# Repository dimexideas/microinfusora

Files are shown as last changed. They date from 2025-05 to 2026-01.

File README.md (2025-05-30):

# Microinfusora de Código Abierto

Micro Infusora de Código Abierto es un proyecto iniciado por un grupo de personas con intereses en desarrollo de tecnología en Ingeniería Biomédica en México.

Desarrollaremos un sistema de microinfusión que sea de código abierto y cuyo enfoque sea el educativo.

## Ojetivos Generales

1. Trabajar con estudiantes, profesores, profesionistas, organizaciones y cualquier otra entidad que quiera participar en el desarrollo de este proyecto.
2. Prepar a estudiantes y profesionistas de carreras de Ingeniería Biomédica y afines a trabajar en proyectos y retos con impacto real en la comunidad.
3. Sentar las bases para proyectos de desarrollo comunitario y servir como un modelo para otros proyectos futuros.

## Objetivos Específicos

1. Desarrollo de un marco teórico para el diseño, desarrollo, pruebas y producción de un dispositivo de microinfusión.
2. Desarrollar las capacidades técnicas para el diseño, desarrollo, pruebas y producción de un dispositivo de microinfusión.
3. Enfoque en seguridad, precisión, consistencia y costo.

## ⚠️ IMPORTANTE ⚠️

En la fase actual del proyecto ( Mayo 2025 ) NO buscamos que el trabajo que desarrollemos tenga una aplicación / uso / pruebas en seres vivos. Para poder avanzar a otro tipo de aplicaciones, será necesario primero el desarrollo de estudios y validaciones alrededor de investigación y validación de la mano de profesionales.

## Participantes

A continuación, la lista de personas que forman parte del proyecto:

* Cesar Terrazas
* Edgar Lopez
* Cesar Ortega
* Gustavo Muñoz
* Luis Duarte
* Sofia Piña 
* Anna Bórquez
* Javier Tanori
* Cristina Ochoa
* Jesus Esquerra
* Ximena Figueroa
* Dereck Palafox
* Victor Burruel  
* Angelica Pesqueira

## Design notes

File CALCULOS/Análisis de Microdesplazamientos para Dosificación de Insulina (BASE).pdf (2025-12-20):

# Análisis de Microdesplazamientos para Dosificación de Insulina con Resolución de 0.1 Unidades

Se necesita mover el embolo 0.0576mm para 0.1 Unidades

Se ocupa:

- Rosca de 1mm por vuelta
- Motor de 200 pasos por vuelta (1.8° por paso)
- Microstepping 16x (logra 3200 pasos por vuelta)

### ¿Cómo se lograron estos resultados?

Se realizaron los siguientes cálculos:

100 Unidades = 1mL

1 Unidades = 0.01mL

0.1 Unidades = 0.001 mL

1 Suponiendo que es de 1mL la jeringa, su diámetro estándar es de 4.7mm

Se usará la siguiente formula:

| Volumen = Area × Longitud
2. La cual convertimos en:
| Longitud = Volumen
| Area
3. Para poder sacar la longitud que tiene que mover el embolo calcularemos solamente el área, ya que, ya contamos con el volumen:
| Area = π × (
| 4.7
| 2

)

| 2 ≈ 17.34mm²
4. Ahora ya que sabemos el área y que 1mL = 1000mm³
| (es el volumen), procedemos a calcular la
longitud que se tiene que mover el embolo:
| Longitud = Volumen
| Area

Longitud =

1000
17.34 ≈ 57.64mm

### ¿Cuánto hay que mover para dosis más pequeñas?

- Para 1 Unidad (0.01mL):
57.64
100 ≈ 0.576mm
- Para 0.1 Unidades (0.001mL): 57.64
1000

≈ 0.0576mm

### ¿Como lograr esto?

Para lograr estos movimientos como lo mencione al principio, se necesitaría una rosca muy fina, el motor de 200 pasos y el microstepping 16x para así poder lograr 3200 pasos por vuelta.

Por ejemplo si usamos las especificaciones que puse al principio, el movimiento por cada micropaso sería:

1mm
3200 = 0.0003125mm

Lo cual es menor que 0.0576 mm, así que nos permite alcanzar la precisión que buscamos; y por ende tenemos el número de micro-pasos del motor necesarios para diferentes dosis:

micropasos =

Distancia que ocupa moverse el embolo correspondiente a la unidad cuanto se mueve el embolo por cada micropaso del motor

micropasos =

0.0576 mm
0.0003125 mm/micropaso

≈ 184

Para 0.1 unidades de insulina → ≈ 184 micro-pasos

Para 1 unidad de insulina → ≈ 1844 micro-pasos

Para 1 mL completo (100 unidades) → ≈ 184,444 micro-pasos

Estos mismos datos pueden ser alterados dependiendo del diámetro, motor, etc. Todo dependiendo de las especificaciones de lo que usaremos (este reporte solo nos sirve para tener una base y cambiar los datos a nuestras necesidades sin perder la precisión que buscamos).

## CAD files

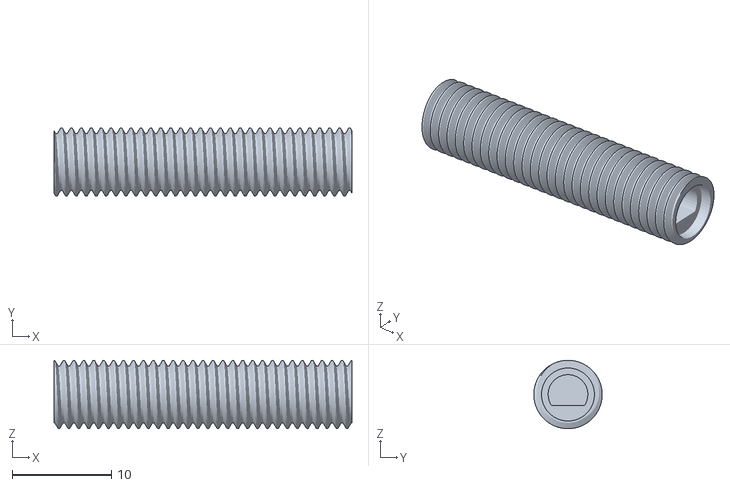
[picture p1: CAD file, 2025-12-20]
DISEÑO/Tornillo_Corregido v1.stl
30.0 x 6.88 x 6.88

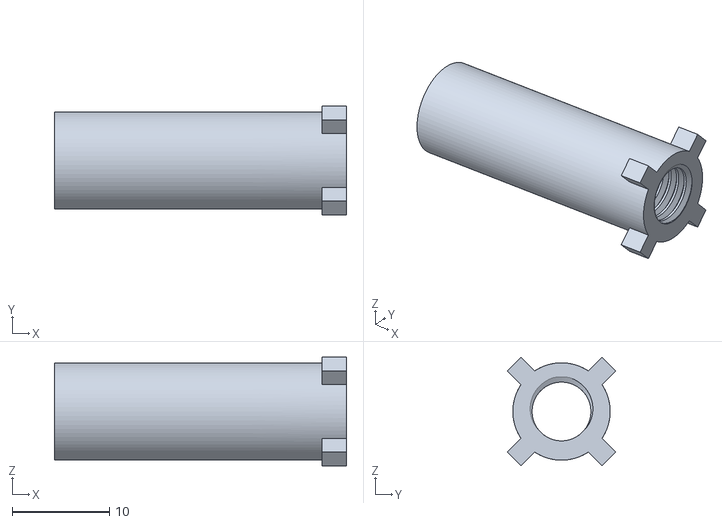
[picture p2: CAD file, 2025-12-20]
DISEÑO/shaft con patitas.stl
30.0 x 11.2 x 11.2

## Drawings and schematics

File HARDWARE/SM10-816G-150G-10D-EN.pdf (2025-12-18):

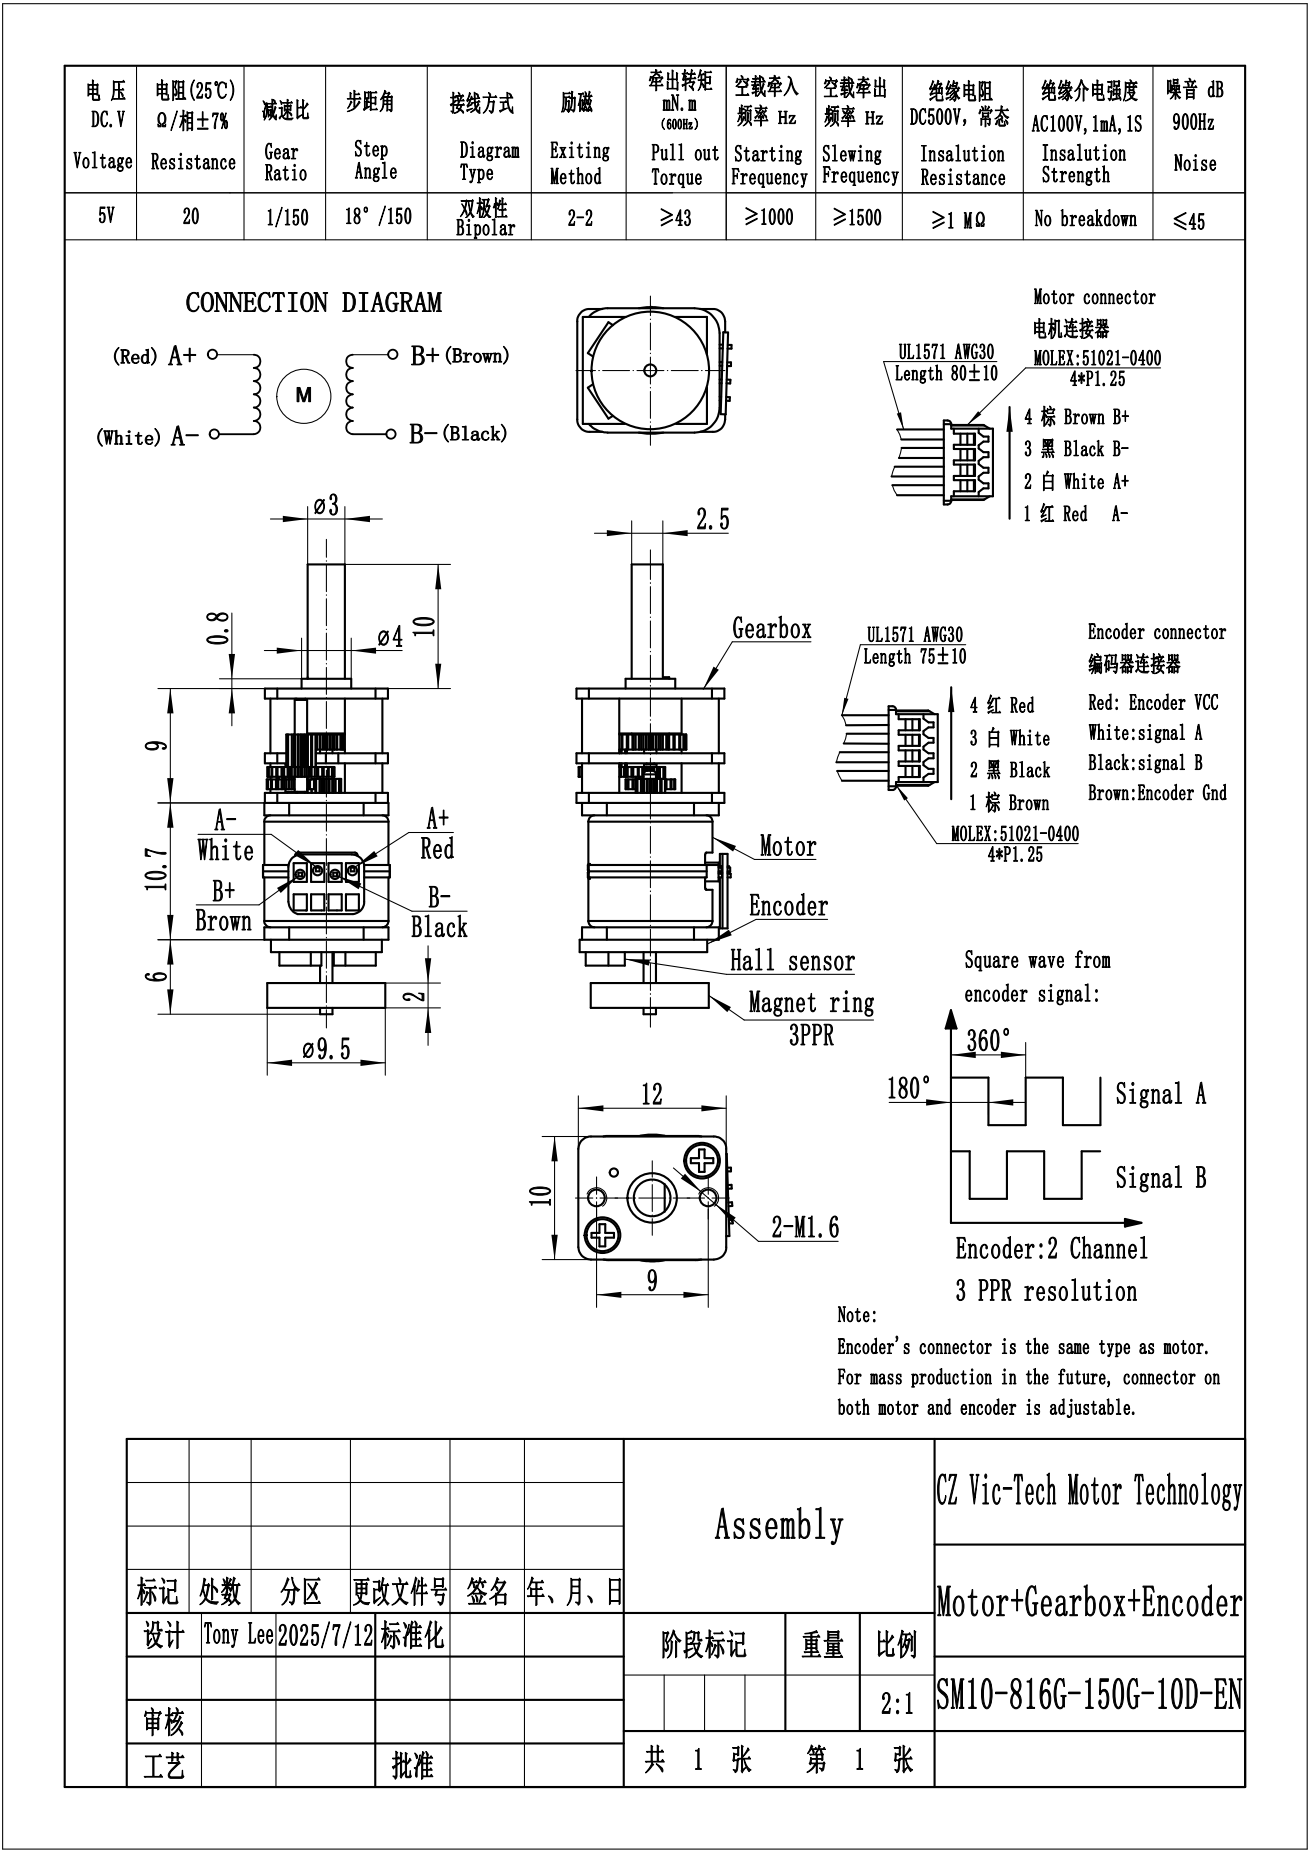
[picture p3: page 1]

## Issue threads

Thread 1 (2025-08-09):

Bug en prototipo en pantalla LCD al iniciar.

bustavo, 2025-08-09:
PROBLEMA:
Al iniciar el programa, muestra primero: "Inicializando microinfusora"
Posterior a esto, la pantalla muestra caracteres que no corresponden a lo esperado por el diagrama de flujo creado.

QUÉ DEBERÍA PASAR:
Después de el mensaje: "Inicializando microinfusora", debería proceder a hacer el chequeo del resto del sistema.

anaximenaf, 2025-08-11:
Al revisar el circuito electrónico, se encontraron 2 cables con falso contacto y fueron reemplazados. Después de esto, el problema se presenta después de mostrar en pantalla "Modo: Automático". También se encontró que al bajar el nivel de batería por debajo de 20% se muestran caracteres aleatorios.

Closed 2025-09-13.

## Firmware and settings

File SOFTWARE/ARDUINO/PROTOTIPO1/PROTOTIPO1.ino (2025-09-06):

//https://wokwi.com/projects/441378105660326913//
#include <LiquidCrystal.h>
#include <EEPROM.h>

// ===================== Hardware =====================
// LCD (RS, E, D4, D5, D6, D7)
LiquidCrystal lcd(12, 11, 5, 4, 3, 2);

// A4988
const int stepPin   = 6;
const int dirPin    = 7;
const int enablePin = 8;
const int ms1Pin = 9;
const int ms2Pin = 10;
const int ms3Pin = A3;

// Botones
const int BTN_BACK   = 13; // Escape/Atrás/Cancelar
const int BTN_OK     = A4; // Confirmar/Entrar
const int BTN_UP     = A5; // Subir
const int BTN_DOWN   = A1; // Bajar

// Otros
const int buzzer = A2;
const int voltagePin = A0; // batería simulada (potenciómetro)

// ===================== Parametría =====================
const int MICROSTEP = 16;            // 1/16 microstepping
const int BASE_STEPS_PER_U = 400;    // pasos por U a paso completo
const int STEPS_PER_U = BASE_STEPS_PER_U * MICROSTEP;

const uint32_t MIN_PULSE_US = 2;     // ancho mínimo de pulso (A4988 ~>1us)
const uint32_t BOLUS_SPEED_US = 900; // intervalo entre pasos para bolo rápido (~1.1k pps)
const uint32_t PRIME_SPEED_US = 1200;
const uint32_t MAX_PRIME_STEPS = 2000; // tope seguridad cebado

// Basal
float basalRate = 0.8f;             // U/h
// Límites
float bolusLimitPerDose = 10.0f;    // U máx por bolo
float bolusDailyLimit   = 50.0f;    // U máx por día (desde arranque)

// Simulación insulina/batería
float insulinRemaining = 300.0f;     // U
float batteryVoltage = 4.2f;         // Calculado desde A0
int   batteryPercent = 100;

// ===================== Persistencia EEPROM =====================
// (usa enteros escalados para evitar float en EEPROM)
const int EE_ADDR_BASAL_10X        = 0;   // uint16 (basal*10)
const int EE_ADDR_LIMIT_DOSE_10X   = 2;   // uint16
const int EE_ADDR_LIMIT_DAILY_10X  = 4;   // uint16

// ===================== Timing / Antirrebote =====================
struct Btn {
  uint8_t pin;
  bool last;
  uint32_t lastChange;
};
Btn btns[4] = {
  {BTN_BACK, true, 0},
  {BTN_OK,   true, 0},
  {BTN_UP,   true, 0},
  {BTN_DOWN, true, 0}
};
const uint16_t DEBOUNCE_MS = 35;
const uint16_t REPEAT_START_MS = 500;
const uint16_t REPEAT_RATE_MS  = 120;

bool pressedEdge(uint8_t index) {
  bool now = digitalRead(btns[index].pin);
  uint32_t t = millis();
  if (now != btns[index].last && (t - btns[index].lastChange) > DEBOUNCE_MS) {
    btns[index].last = now;
    btns[index].lastChange = t;
    // Botones con PULLUP: LOW = presionado
    return (now == LOW);
  }
  return false;
}
bool heldRepeat(uint8_t index) {
  // auto-repetición cuando se mantiene presionado
  static uint32_t startHeld[4] = {0,0,0,0};
  static uint32_t lastRpt[4]   = {0,0,0,0};
  bool now = (digitalRead(btns[index].pin) == LOW);
  uint32_t t = millis();
  if (pressedEdge(index)) { startHeld[index] = t; lastRpt[index]=t; return true; }
  if (now) {
    if (t - startHeld[index] > REPEAT_START_MS && t - lastRpt[index] > REPEAT_RATE_MS) {
      lastRpt[index] = t;
      return true;
    }
  }
  return false;
}

// ===================== Motor no bloqueante =====================
struct MotorJob {
  bool active = false;
  uint32_t stepIntervalUs = 1000;
  uint32_t lastStepUs = 0;
  uint32_t stepsRemaining = 0;
  uint8_t  type = 0; // 0=none,1=PRIME,2=BOLUS_FAST,3=BOLUS_EXT,4=BASAL
};
MotorJob job;

void motorEnable(bool en) { digitalWrite(enablePin, en ? LOW : HIGH); } // A4988 EN activo bajo
void motorPulse() {
  // Un pulso (HIGH->LOW). En Arduino, la pareja suele durar >1us sin delay
  digitalWrite(stepPin, HIGH);
  // delayMicroseconds(MIN_PULSE_US); // opcional
  digitalWrite(stepPin, LOW);
}
void startJob(uint8_t type, uint32_t steps, uint32_t intervalUs) {
  job.type = type;
  job.stepsRemaining = steps;
  job.stepIntervalUs = intervalUs;
  job.lastStepUs = micros();
  job.active = (steps > 0);
  motorEnable(true);
  digitalWrite(dirPin, HIGH);
}
void stopJob() {
  job.active = false;
  job.stepsRemaining = 0;
  job.type = 0;
  motorEnable(false);
}
void serviceMotor() {
  if (!job.active) return;
  uint32_t now = micros();
  if (now - job.lastStepUs >= job.stepIntervalUs) {
    motorPulse();
    job.lastStepUs = now;
    if (job.stepsRemaining > 0) {
      job.stepsRemaining--;
      if (job.stepsRemaining == 0) {
        stopJob();
      }
    }
  }
}

// ===================== Basal distribuida =====================
struct BasalTask {
  bool enabled = false;
  uint32_t stepIntervalUs = 0; // calculado desde basalRate
  uint32_t lastStepUs = 0;
} basalTask;

void recalcBasal() {
  if (basalRate <= 0.0f) { basalTask.enabled=false; return; }
  // pasos/hora = basalRate * STEPS_PER_U
  // intervalo por paso (us) = 3600e6 / pasosHora
  double stepsPerHour = (double)basalRate * (double)STEPS_PER_U;
  if (stepsPerHour < 1.0) stepsPerHour = 1.0;
  basalTask.stepIntervalUs = (uint32_t)(3600000000.0 / stepsPerHour);
  basalTask.enabled = true;
  basalTask.lastStepUs = micros();
}

void serviceBasal() {
  if (!basalTask.enabled || job.active) return; // no competir con un bolo/cebado
  uint32_t now = micros();
  if (now - basalTask.lastStepUs >= basalTask.stepIntervalUs) {
    // entregar 1 paso
    motorEnable(true);
    digitalWrite(dirPin, HIGH);
    motorPulse();
    basalTask.lastStepUs = now;
    // contabilidad de insulina
    insulinRemaining -= (1.0f / (float)STEPS_PER_U);
  }
}

// ===================== Bolo extendido / automático =====================
struct ExtendedBolus {
  bool active=false;
  uint32_t totalSteps=0;
  uint32_t stepsDelivered=0;
  uint32_t stepIntervalUs=0;
  uint32_t lastStepUs=0;
  uint32_t endMillis=0;
  bool repeating=false;
  uint32_t repeatEveryMs=0;
} ext;

void startExtended(float units, uint32_t durationMin) {
  if (units <= 0) return;
  uint32_t steps = (uint32_t)(units * STEPS_PER_U + 0.5f);
  if (steps == 0) return;
  uint64_t totalUs = (uint64_t)durationMin * 60000000ULL;
  uint32_t intervalUs = (uint32_t)(totalUs / steps);
  ext.active=true;
  ext.totalSteps = steps;
  ext.stepsDelivered = 0;
  ext.stepIntervalUs = (intervalUs == 0 ? 1 : intervalUs);
  ext.lastStepUs = micros();
  ext.endMillis = millis() + durationMin*60000UL;
}

void serviceExtended() {
  if (!ext.active || job.active) return; // no solapar con job rápido
  uint32_t nowUs = micros();
  if (nowUs - ext.lastStepUs >= ext.stepIntervalUs) {
    motorEnable(true);
    digitalWrite(dirPin, HIGH);
    motorPulse();
    ext.lastStepUs = nowUs;
    ext.stepsDelivered++;
    insulinRemaining -= (1.0f / (float)STEPS_PER_U);
    if (ext.stepsDelivered >= ext.totalSteps) {
      ext.active = false;
      motorEnable(false);
      if (ext.repeating && ext.repeatEveryMs > 0) {
        // reprogramar
        startExtended((float)ext.totalSteps/(float)STEPS_PER_U, (ext.repeatEveryMs/60000UL));
      }
    }
  }
}

void cancelAnyInfusion() {
  stopJob();
  ext.active = false;
  motorEnable(false);
  tone(buzzer, 1900, 120);
}

// ===================== Utilidades =====================
void beepOK()   { tone(buzzer, 1400, 80); }
void beepWarn() { tone(buzzer, 900,  120); }
void beepErr()  { tone(buzzer, 500,  200); }

void readBattery() {
  int v = analogRead(voltagePin);
  // Simula 3.0V .. 4.2V en el potenciómetro
  batteryVoltage = map(v, 0, 1023, 300, 420)/100.0;
  batteryPercent = map(v, 0, 1023, 0, 100);
  if (batteryPercent < 0) batteryPercent=0;
  if (batteryPercent > 100) batteryPercent=100;
}

// ===================== Menú / Estados =====================
enum State {
  ST_HOME,
  ST_MENU,
  ST_PRIME,
  ST_BOLUS_MANUAL,
  ST_BOLUS_MANUAL_EXTDUR,
  ST_BOLUS_CANCEL,
  ST_LIMITS,
  ST_BASAL,
  ST_AUTO_PROG,         // “X U en Y min, repetir cada Z”
  ST_CONFIRM_START
};
State state = ST_HOME;

int menuIndex = 0;
const int MENU_COUNT = 7;

float tmpUnits = 1.0f;   // buffer para selección de U
int   tmpMinutes = 10;   // buffer para selección de minutos
int   tmpRepeatMin = 0;  // 0 = no repetir

// Estadística simple
float dailyDelivered = 0.0f;

void drawHome() {
  lcd.clear();
  lcd.setCursor(0,0);
  lcd.print("Bat ");
  lcd.print(batteryPercent);
  lcd.print("%  Ins ");
  if (insulinRemaining < 0) insulinRemaining = 0;
  lcd.print((int)insulinRemaining);
  lcd.print("U");
  lcd.setCursor(0,1);
  lcd.print(ext.active ? "EXBolus ON   " : (job.active ? "Bolo/Cebado  " : "Listo         "));
}

void drawMenu() {
  lcd.clear();
  const char* items[MENU_COUNT] = {
    "Cebado",
    "Bolo manual",
    "Cancelar bolo",
    "Limitar bolo",
    "Infusion basal",
    "Auto programar",
    "Salir"
  };
  // Mostrar 2 líneas con cursor
  int next = (menuIndex+1) % MENU_COUNT;
  lcd.setCursor(0,0); lcd.print(">");
  lcd.print(items[menuIndex]);
  lcd.setCursor(0,1); lcd.print(" ");
  lcd.print(items[next]);
}

void eepromLoad() {
  uint16_t b10 = 0, l110=0, l210=0;
  EEPROM.get(EE_ADDR_BASAL_10X, b10);
  EEPROM.get(EE_ADDR_LIMIT_DOSE_10X, l110);
  EEPROM.get(EE_ADDR_LIMIT_DAILY_10X, l210);
  if (b10 > 0 && b10 < 500) basalRate = b10 / 10.0f;
  if (l110 >= 5 && l110 <= 500) bolusLimitPerDose = l110 / 10.0f;
  if (l210 >= 10 && l210 <= 1000) bolusDailyLimit = l210 / 10.0f;
  recalcBasal();
}

void eepromSave() {
  uint16_t b10 = (uint16_t)(basalRate*10.0f + 0.5f);
  uint16_t l110= (uint16_t)(bolusLimitPerDose*10.0f + 0.5f);
  uint16_t l210= (uint16_t)(bolusDailyLimit*10.0f + 0.5f);
  EEPROM.put(EE_ADDR_BASAL_10X,       b10);
  EEPROM.put(EE_ADDR_LIMIT_DOSE_10X,  l110);
  EEPROM.put(EE_ADDR_LIMIT_DAILY_10X, l210);
}

// ===================== Setup =====================
void setup() {
  pinMode(stepPin, OUTPUT);
  pinMode(dirPin, OUTPUT);
  pinMode(enablePin, OUTPUT);
  pinMode(ms1Pin, OUTPUT);
  pinMode(ms2Pin, OUTPUT);
  pinMode(ms3Pin, OUTPUT);

  pinMode(BTN_BACK, INPUT_PULLUP);
  pinMode(BTN_OK,   INPUT_PULLUP);
  pinMode(BTN_UP,   INPUT_PULLUP);
  pinMode(BTN_DOWN, INPUT_PULLUP);

  pinMode(buzzer, OUTPUT);

  // Microstepping 1/16
  digitalWrite(ms1Pin, HIGH);
  digitalWrite(ms2Pin, HIGH);
  digitalWrite(ms3Pin, HIGH);
  motorEnable(false);

  lcd.begin(16,2);
  lcd.print("Microinfusora");
  lcd.setCursor(0,1); lcd.print("Iniciando...");
  delay(900);
  eepromLoad();
  drawHome();
}

// ===================== Loop =====================
void loop() {
  // servicios en background
  readBattery();
  serviceMotor();
  serviceExtended();
  serviceBasal();

  // bloqueo por batería crítica
  if (batteryPercent < 5 || batteryVoltage < 3.30) {
    cancelAnyInfusion();
    lcd.setCursor(0,1);
    lcd.print("Bateria critica");
    delay(5);
    return;
  }

  // ---- Navegación / estados ----
  switch (state) {
    case ST_HOME: {
      // Entrar a menú
      if (pressedEdge(1)) { // OK
        state = ST_MENU;
        menuIndex = 0;
        drawMenu();
        beepOK();
      }
      // Cancelación rápida
      if (pressedEdge(0)) {
        cancelAnyInfusion();
        drawHome();
      }
      // Scroll para refrescar pantalla
      if (heldRepeat(2) || heldRepeat(3)) {
        drawHome();
      }
    } break;

    case ST_MENU: {
      if (heldRepeat(2)) { // UP
        menuIndex = (menuIndex - 1 + MENU_COUNT) % MENU_COUNT;
        drawMenu();
      }
      if (heldRepeat(3)) { // DOWN
        menuIndex = (menuIndex + 1) % MENU_COUNT;
        drawMenu();
      }
      if (pressedEdge(1)) { // OK
        beepOK();
        switch (menuIndex) {
          case 0: state = ST_PRIME; break;
          case 1: state = ST_BOLUS_MANUAL; tmpUnits = 1.0f; break;
          case 2: state = ST_BOLUS_CANCEL; break;
          case 3: state = ST_LIMITS; break;
          case 4: state = ST_BASAL; break;
          case 5: state = ST_AUTO_PROG; tmpUnits=1.0f; tmpMinutes=10; tmpRepeatMin=0; break;
          case 6: state = ST_HOME; drawHome(); break;
        }
      }
      if (pressedEdge(0)) { // BACK
        state = ST_HOME; drawHome();
      }
    } break;

    case ST_PRIME: {
      // Cebado configurable por pasos (U) o tiempo
      static bool asUnits = true; // alterna con OK
      static float primeUnits = 0.5f;
      static int   primeSecs  = 10;

      lcd.setCursor(0,0);
      lcd.print("Cebado ");
      lcd.print(asUnits ? "Unid" : "Tiempo");
      lcd.setCursor(0,1);
      if (asUnits) {
        lcd.print(primeUnits,1); lcd.print("U  OK=Go ");
      } else {
        lcd.print(primeSecs); lcd.print("s  OK=Go ");
      }

      if (heldRepeat(2)) { // UP
        if (asUnits) { if (primeUnits < 5.0f) primeUnits += 0.1f; }
        else          { if (primeSecs  < 60)   primeSecs  += 1;   }
        lcd.setCursor(0,1); lcd.print("                ");
      }
      if (heldRepeat(3)) { // DOWN
        if (asUnits) { if (primeUnits > 0.1f) primeUnits -= 0.1f; }
        else          { if (primeSecs  > 1)    primeSecs  -= 1;   }
        lcd.setCursor(0,1); lcd.print("                ");
      }
      if (pressedEdge(1)) { // OK -> iniciar
        uint32_t steps = asUnits ? (uint32_t)(primeUnits*STEPS_PER_U+0.5f)
                                 : (uint32_t)((1000000UL*primeSecs)/PRIME_SPEED_US);
        if (steps > MAX_PRIME_STEPS) steps = MAX_PRIME_STEPS;
        if (insulinRemaining < (float)steps/(float)STEPS_PER_U) { beepErr(); break; }
        startJob(1, steps, PRIME_SPEED_US);
        insulinRemaining -= (float)steps/(float)STEPS_PER_U;
        dailyDelivered   += (float)steps/(float)STEPS_PER_U;
        state = ST_HOME; drawHome();
      }
      if (pressedEdge(0)) { // BACK
        state = ST_MENU; drawMenu();
      }
      // alterna unidades/tiempo con pulsación larga OK
      static uint32_t lastOk = 0;
      if (digitalRead(BTN_OK)==LOW) {
        if (millis()-lastOk>700) { asUnits = !asUnits; lastOk=millis(); lcd.clear(); }
      } else lastOk=millis();
    } break;

    case ST_BOLUS_MANUAL: {
      // Paso 1: elegir unidades
      lcd.setCursor(0,0); lcd.print("Bolo manual U:");
      lcd.setCursor(0,1); lcd.print("  "); lcd.print(tmpUnits,1); lcd.print("U");
      if (heldRepeat(2)) { if (tmpUnits < bolusLimitPerDose) tmpUnits += 0.1f; }
      if (heldRepeat(3)) { if (tmpUnits > 0.1f)              tmpUnits -= 0.1f; }
      if (pressedEdge(1)) { // OK -> escoger tipo
        state = ST_BOLUS_MANUAL_EXTDUR;
        lcd.clear();
      }
      if (pressedEdge(0)) { state = ST_MENU; drawMenu(); }
    } break;

    case ST_BOLUS_MANUAL_EXTDUR: {
      // Elegir rápido o extendido (duración)
      static bool extended = false;
      lcd.setCursor(0,0); lcd.print(extended ? "Extendido" : "Rapido");
      lcd.setCursor(0,1);
      if (extended) { lcd.print("Dur: "); lcd.print(tmpMinutes); lcd.print(" min"); }
      else          { lcd.print("OK=Iniciar  "); }

      if (heldRepeat(2)) { // UP
        if (extended && tmpMinutes < 240) tmpMinutes++;
        else extended = true;
      }
      if (heldRepeat(3)) { // DOWN
        if (extended && tmpMinutes > 1) tmpMinutes--;
        else extended = false;
      }
      if (pressedEdge(1)) { // OK -> iniciar
        // Chequeos de seguridad
        if (tmpUnits > bolusLimitPerDose) { beepErr(); break; }
        if (dailyDelivered + tmpUnits > bolusDailyLimit) { beepErr(); break; }
        if (insulinRemaining < tmpUnits) { beepErr(); break; }

        if (extended) {
          startExtended(tmpUnits, tmpMinutes);
          dailyDelivered   += tmpUnits;
          insulinRemaining -= tmpUnits;
        } else {
          uint32_t steps = (uint32_t)(tmpUnits*STEPS_PER_U+0.5f);
          startJob(2, steps, BOLUS_SPEED_US);
          dailyDelivered   += tmpUnits;
          insulinRemaining -= tmpUnits;
        }
        state = ST_HOME; drawHome();
      }
      if (pressedEdge(0)) { state = ST_BOLUS_MANUAL; lcd.clear(); }
    } break;

    case ST_BOLUS_CANCEL: {
      cancelAnyInfusion();
      state = ST_MENU; drawMenu();
    } break;

    case ST_LIMITS: {
      static uint8_t page=0; // 0=per-dose,1=daily
      lcd.setCursor(0,0);
      lcd.print(page==0 ? "Limite x Bolo" : "Limite Diario");
      lcd.setCursor(0,1);
      lcd.print(page==0 ? bolusLimitPerDose : bolusDailyLimit);
      lcd.print("U     ");

      if (heldRepeat(2)) { if (page==0) bolusLimitPerDose += 0.5f; else bolusDailyLimit += 1.0f; }
      if (heldRepeat(3)) { if (page==0 && bolusLimitPerDose>0.5f) bolusLimitPerDose -= 0.5f;
                           if (page==1 && bolusDailyLimit>1.0f)   bolusDailyLimit   -= 1.0f; }
      if (pressedEdge(1)) { // OK -> cambiar página o guardar
        if (page==0) page=1;
        else { eepromSave(); page=0; beepOK(); }
        lcd.clear();
      }
      if (pressedEdge(0)) { state = ST_MENU; drawMenu(); }
    } break;

    case ST_BASAL: {
      lcd.setCursor(0,0); lcd.print("Basal: "); lcd.print(basalRate,1); lcd.print("U/h");
      lcd.setCursor(0,1); lcd.print("OK=Guardar  ");
      if (heldRepeat(2)) { if (basalRate < 5.0f) basalRate += 0.1f; }
      if (heldRepeat(3)) { if (basalRate > 0.0f) basalRate -= 0.1f; }
      if (pressedEdge(1)) { eepromSave(); recalcBasal(); state = ST_MENU; drawMenu(); }
      if (pressedEdge(0)) { state = ST_MENU; drawMenu(); }
    } break;

    case ST_AUTO_PROG: {
      // “manda X U en Y min, repetir cada Z min (0=una vez)”
      lcd.setCursor(0,0);
      lcd.print("U:"); lcd.print(tmpUnits,1);
      lcd.print(" T:"); lcd.print(tmpMinutes); lcd.print("m");
      lcd.setCursor(0,1);
      lcd.print("Rep: "); lcd.print(tmpRepeatMin); lcd.print("m  OK=Go");

      if (heldRepeat(2)) {
        // ciclo de edición: U -> T -> Rep
        static uint8_t field=0;
        // rotación de campo con OK largo
        if (digitalRead(BTN_OK)==LOW) { field=(field+1)%3; delay(180); }
        if (field==0 && tmpUnits < bolusLimitPerDose) tmpUnits+=0.1f;
        if (field==1 && tmpMinutes < 600) tmpMinutes++;
        if (field==2 && tmpRepeatMin < 600) tmpRepeatMin++;
      }
      if (heldRepeat(3)) {
        static uint8_t field=0;
        if (digitalRead(BTN_OK)==LOW) { field=(field+1)%3; delay(180); }
        if (field==0 && tmpUnits > 0.1f) tmpUnits-=0.1f;
        if (field==1 && tmpMinutes > 1) tmpMinutes--;
        if (field==2 && tmpRepeatMin > 0) tmpRepeatMin--;
      }
      if (pressedEdge(1)) {
        if (tmpUnits > bolusLimitPerDose) { beepErr(); break; }
        if (dailyDelivered + tmpUnits > bolusDailyLimit) { beepErr(); break; }
        if (insulinRemaining < tmpUnits) { beepErr(); break; }
        // programar como bolo extendido
        startExtended(tmpUnits, tmpMinutes);
        dailyDelivered   += tmpUnits;
        insulinRemaining -= tmpUnits;
        // configurar repetición
        ext.repeating = (tmpRepeatMin > 0);
        ext.repeatEveryMs = (uint32_t)tmpRepeatMin * 60000UL;
        state = ST_HOME; drawHome();
      }
      if (pressedEdge(0)) { state = ST_MENU; drawMenu(); }
    } break;

    case ST_CONFIRM_START:
      // (no usado en esta versión; se dejó hueco si quieres pantallas de confirmación)
      state = ST_HOME;
      break;
  }
}

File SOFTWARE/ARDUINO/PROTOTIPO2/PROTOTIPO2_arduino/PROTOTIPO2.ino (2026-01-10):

// https://wokwi.com/projects/449649246302984193//
#include <EEPROM.h>
#include <LiquidCrystal.h>

// LCD (RS, E, D4, D5, D6, D7)
// LCD (RS, E, D4, D5, D6, D7)
// LCD (RS, E, D4, D5, D6, D7)
LiquidCrystal lcd(12, 13, 4, 5, 6, 7);

// A4988
// A4988
// A4988
const int stepPin = 9;   // PASOS. Cada pulso, avanza un paso.
const int dirPin = 8;    // DIRECCIÓN. 0 = Antihorario, 1 = Horario.
const int enablePin = 2; // ACTIVACION. 0 = Activo, 1 = Inactivo.
// const int ms1Pin = 9;    // TAMAÑO DE PASO. 0 = 1/16, 1 = 1/8, 2 = 1/4, 3 = 1/2, 4 = 1/1.
// const int ms2Pin = 10;   // TAMAÑO DE PASO. 0 = 1/16, 1 = 1/8, 2 = 1/4, 3 = 1/2, 4 = 1/1.
// const int ms3Pin = A3;   // TAMAÑO DE PASO. 0 = 1/16, 1 = 1/8, 2 = 1/4, 3 = 1/2, 4 = 1/1.

// VARIABLES MOTOR & INSULINA.
// VARIABLES MOTOR & INSULINA.
// VARIABLES MOTOR & INSULINA.
int curStep = 0;         // PASO ACTUAL.
const float reservoirCapacity = 300; // CONFIGURACION DE CAPACIDAD DE RESERVORIO.
float reservoirLevel = reservoirCapacity; // NIVEL DE RESERVORIO.
float stepUnits = 0.1; // UNIDADES DE INSULINA POR PASOS DE MOTOR.

// VARIABLES PERFIL BASAL.
// VARIABLES PERFIL BASAL.
// VARIABLES PERFIL BASAL.

const uint8_t BASAL_SLOTS = 48;
const uint8_t MIN_PER_SLOT = 30;
const uint16_t VALUE10_MAX = 100;

uint16_t basal10[BASAL_SLOTS];
uint8_t editingStartSlot = 0;
uint8_t editingEndSlot = 0;
uint16_t editingValue10 = 0;

void lcdPrintHHMM_fromSlot(uint8_t slot) {
  uint16_t minutes = (uint16_t)slot * MIN_PER_SLOT; // 0..1440
  uint8_t hh = minutes / 60;
  uint8_t mm = minutes % 60;

  if (hh < 10) lcd.print("0");
  lcd.print(hh);
  lcd.print(":");
  if (mm < 10) lcd.print("0");
  lcd.print(mm);
}

void nudgeEndSlot(int8_t dir) { // dir = +1 or -1
  int16_t next = (int16_t)editingEndSlot + dir;

  if (next < (int16_t)editingStartSlot) next = editingStartSlot;
  if (next > 48) next = 48;

  editingEndSlot = (uint8_t)next;
}

void lcdPrintValue10(uint16_t v10) {
  uint16_t whole = v10 / 10;
  uint8_t frac = v10 % 10;
  lcd.print(whole);
  lcd.print(".");
  lcd.print(frac);
}

void nudgeValue10(int8_t dir) { // dir = +1 or -1
  int32_t next = (int32_t)editingValue10 + dir;

  if (next < 0) next = 0;
  if (next > VALUE10_MAX) next = VALUE10_MAX;

  editingValue10 = (uint16_t)next;
}

bool commitRangeAndAdvance(bool resetValueToZero = true) {
  // Must be at least one 30-min slot
  if (editingEndSlot <= editingStartSlot) return false;

  // Fill basal10 slots in the range [start, end)
  // editingEndSlot can be 48; last valid index is 47
  for (uint8_t i = editingStartSlot; i < editingEndSlot; i++) {
    if (i < BASAL_SLOTS) basal10[i] = editingValue10;
  }

  // Advance start to end
  editingStartSlot = editingEndSlot;

  // Prepare for next segment
  editingEndSlot = editingStartSlot;

  if (resetValueToZero) editingValue10 = 0;

  return true;
}

// Botones
// Botones
// Botones
const int BTN_BACK = 10; // ESC  // Escape/ Atrás / Cancelar
const int BTN_OK = 11;   // ACT  // Confirmar / Entrar
const int BTN_UP = A5;   // UP   // Subir
const int BTN_DOWN = A1; // DOWN / Bajar

// Otros
// Otros
// Otros
const int buzzer = A2;     // Para alarmas
const int voltagePin = A0; // Batería simulada (potenciómetro)

// ===================== Timing de botones / Antirrebote =====================
// ===================== Timing de botones / Antirrebote =====================
// ===================== Timing de botones / Antirrebote =====================
struct Btn {
  uint8_t pin;
  bool last;
  uint32_t lastChange;
};

Btn btns[4] = {{BTN_BACK, true, 0},
               {BTN_OK, true, 0},
               {BTN_UP, true, 0},
               {BTN_DOWN, true, 0}};

const uint16_t DEBOUNCE_MS = 100;
const uint16_t REPEAT_START_MS = 0;
const uint16_t REPEAT_RATE_MS = 0;

bool pressedEdge(uint8_t index) {
  bool now = digitalRead(btns[index].pin);
  uint32_t t = millis();
  if (now != btns[index].last && (t - btns[index].lastChange) > DEBOUNCE_MS) {
    btns[index].last = now;
    btns[index].lastChange = t;
    return (now == LOW); // Botones con PULLUP: LOW = presionado
  }
  return false;
}

bool heldRepeat(uint8_t index) {
  // auto-repetición cuando se mantiene presionado
  static uint32_t startHeld[4] = {0, 0, 0, 0};
  static uint32_t lastRpt[4] = {0, 0, 0, 0};
  bool now = (digitalRead(btns[index].pin) == LOW);
  uint32_t t = millis();
  if (pressedEdge(index)) {
    startHeld[index] = t;
    lastRpt[index] = t;
    return true;
  }
  if (now) {
    if (t - startHeld[index] > REPEAT_START_MS &&
        t - lastRpt[index] > REPEAT_RATE_MS) {
      lastRpt[index] = t;
      return true;
    }
  }
  return false;
}

// ===================== Alarmas audibles =====================
// ===================== Alarmas audibles =====================
// ===================== Alarmas audibles =====================
void beepOK() { tone(buzzer, 1400, 80); }
void beepWarn() { tone(buzzer, 900, 120); }
void beepErr() { tone(buzzer, 500, 200); }
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

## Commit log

2025-05-30 Personalización de archivo README
2025-05-30 Actualización de README
2025-05-30 Modifique el archivo con mi nombre :)
2025-05-30 modifiqué el README
2025-05-30 Actualización de conflicto
2025-08-09 Agregué archivo en proceso de prototipo Arduino
2025-09-06 Actualización orden de estados.
2025-09-13 Actualización de menú base.
2025-12-07 Fix issue #3. El loop en menú no contabilizaba correctamente pasar del elemento 0 al último al presionar el botón para arriba y del último elemento al primero al presionar el botón para abajo. Se inc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
    [PROTOTIPO2.ino]
2025-12-18 Agregué funcionalidad de CEBADO. close #4
2025-12-18 Agregué data sheet de motor
2025-12-20 Actualización de funciones de movimiento de motor.
2025-12-20 Actualización de variables de reservorio de insulina
2025-12-20 Agrego carpeta calculos para documentación y análisis del proyecto
2025-12-20 agregue el stl del shaft con las guías
    [shaft con patitas.stl]
2025-12-20 stl tornillo
    [Tornillo_Corregido v1.stl]
2025-12-20 reacomode archivos
    [shaft con patitas.stl]
2025-12-20 reacomode archivo
    [shaft con patitas.stl]
2026-01-10 Creación de perfil basal. Close #6
2026-01-10 Actualización de wowki
2026-01-10 agregué video de prototipo físico 2 e instrucciones de cómo adaptar el código
